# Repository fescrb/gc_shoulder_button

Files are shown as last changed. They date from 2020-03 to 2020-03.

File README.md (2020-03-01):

# GameCube Shoulder Button

This project's aim is to create a model & CAD files of a GameCube shoulder button. 

A 1:1 correspondance is not required. A simple 3D printable model that can be inserted in the hole for the shoulder button and action it in a similar fashion is all that is required.

After the first objective is achieved. The aim is to parameterize travel times for shoulder button activation/deactivation and change them.

# The button

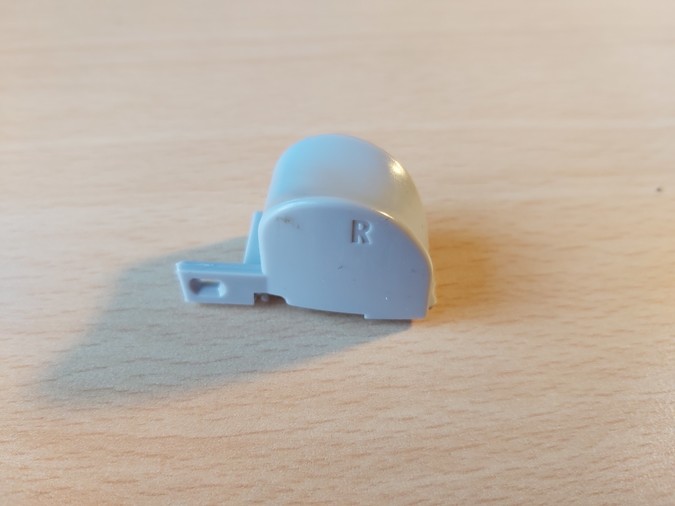
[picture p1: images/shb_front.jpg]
Shoulder Cap - Front


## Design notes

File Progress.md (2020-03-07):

# Progress

# Test 1:

The narrow corner is too big to fit the hole in the controller. Will narrow it down.

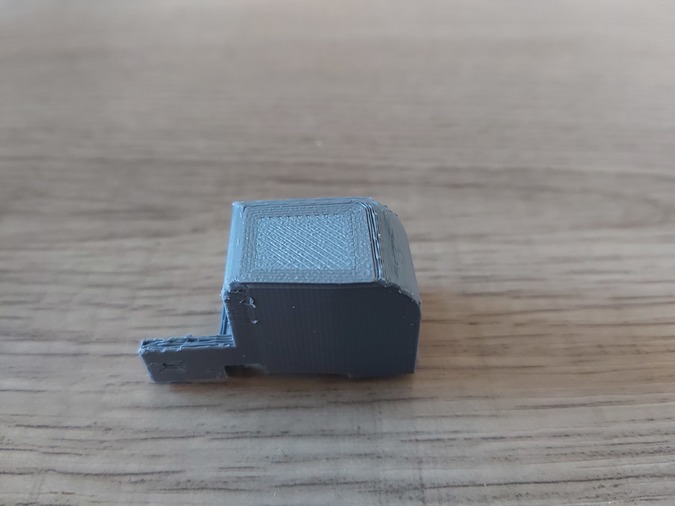
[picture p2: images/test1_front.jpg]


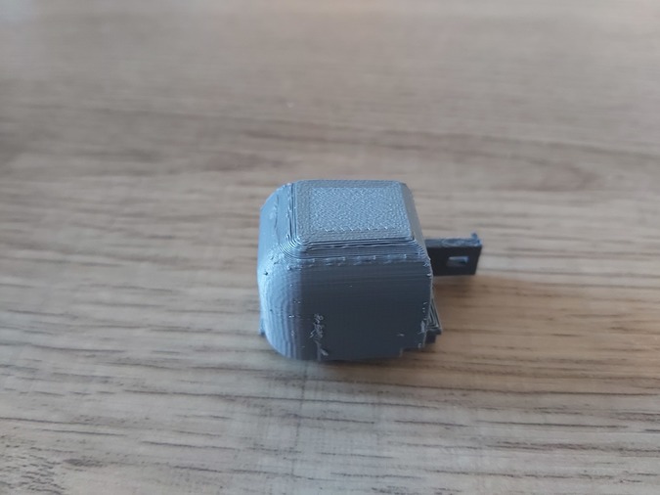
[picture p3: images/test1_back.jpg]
Back


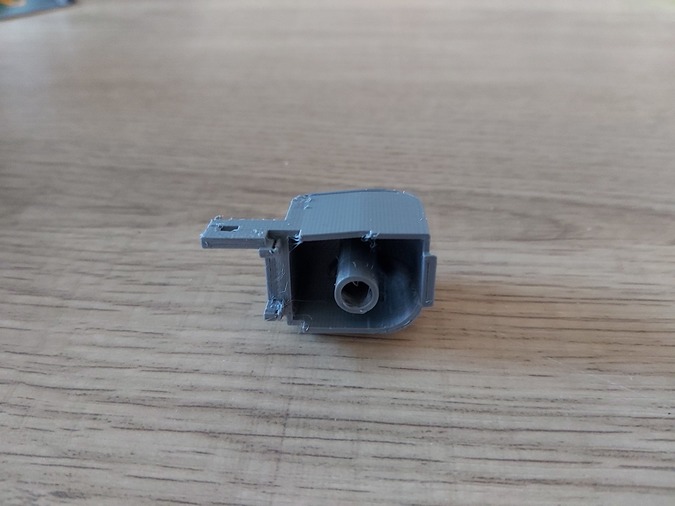
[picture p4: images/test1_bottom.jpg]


# Test 2:

Didn't quite get the top smooth but I did manage to fit the button in the controller.

The clips to attach the spring base are too flimsy at 0.5mm length, I will increase it to 1.5mm and increase the size of the hole that keeps the metal in place.

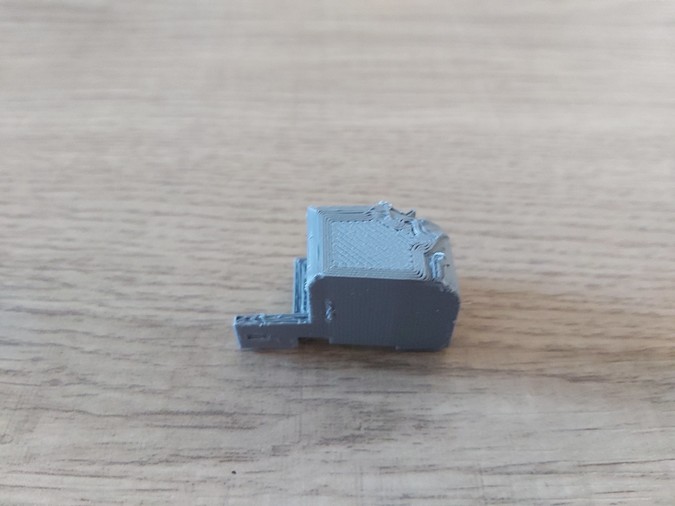
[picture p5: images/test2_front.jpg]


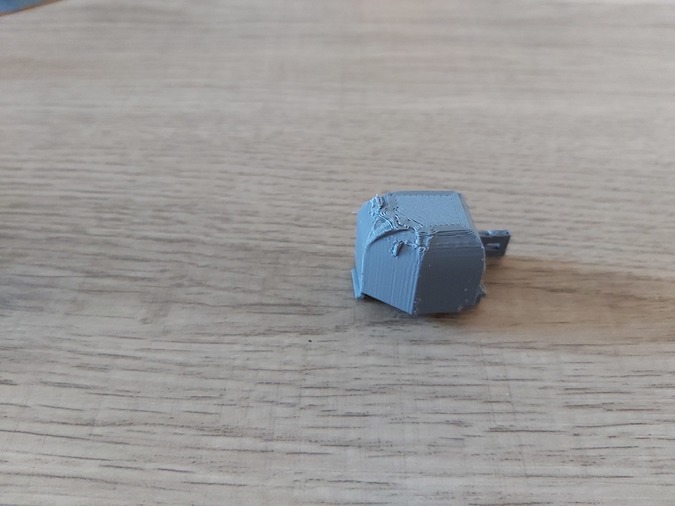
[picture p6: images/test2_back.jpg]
Back


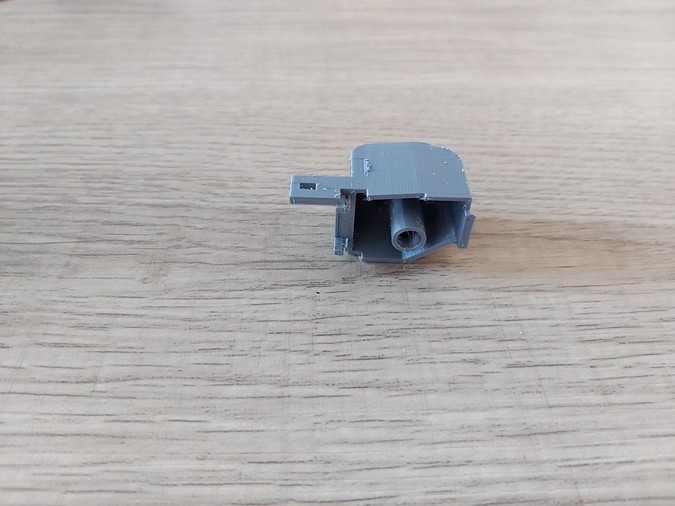
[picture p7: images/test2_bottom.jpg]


# Test 3:

I increased the depth of the clips. However they snapped when trying to connect the metal rail. Unfortunately I forgot to make the cutout go all the way through but I think that had no effect. I'll try making the gap larger to make it easier to slide in the bar, and hopefully less likely to snap.

# Test 4:

The changes to the clips fixed the issue. Now it fits into the slot but when the plastic lid is closed properly it gets stuck. For the next test I will remove one millimeter of depth through the button.

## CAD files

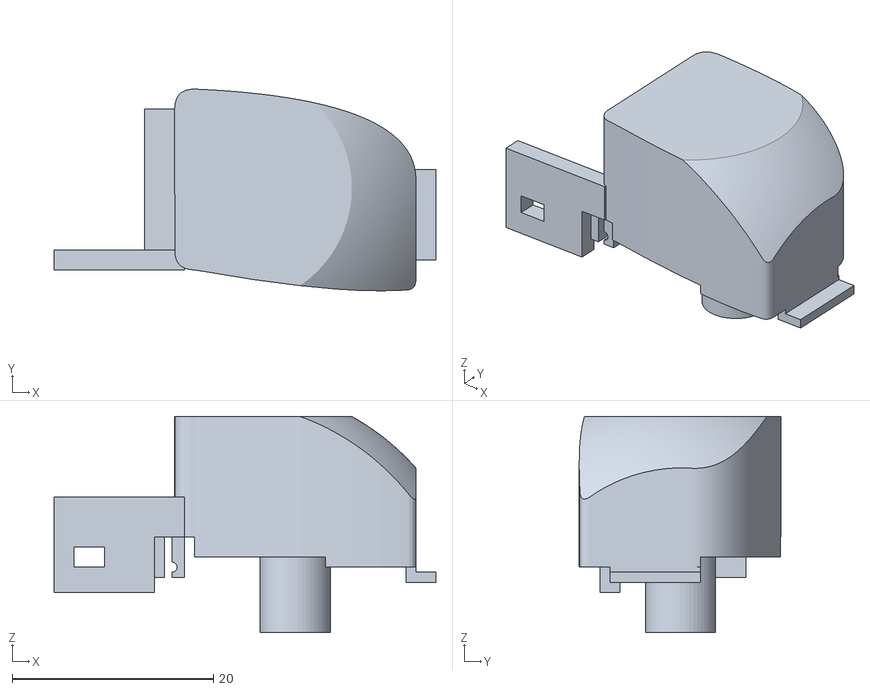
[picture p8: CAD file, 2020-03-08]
shoulder_r_low_action.stl
38.0 x 20.1 x 21.5

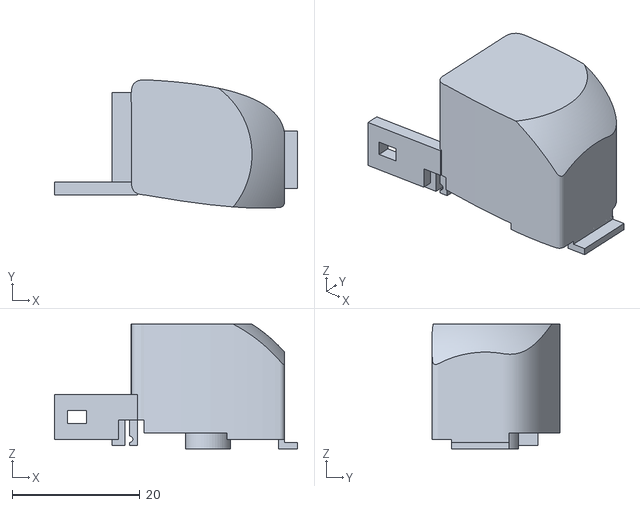
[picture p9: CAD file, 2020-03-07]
shoulder_r_new_shape.stl
38.0 x 20.1 x 19.5

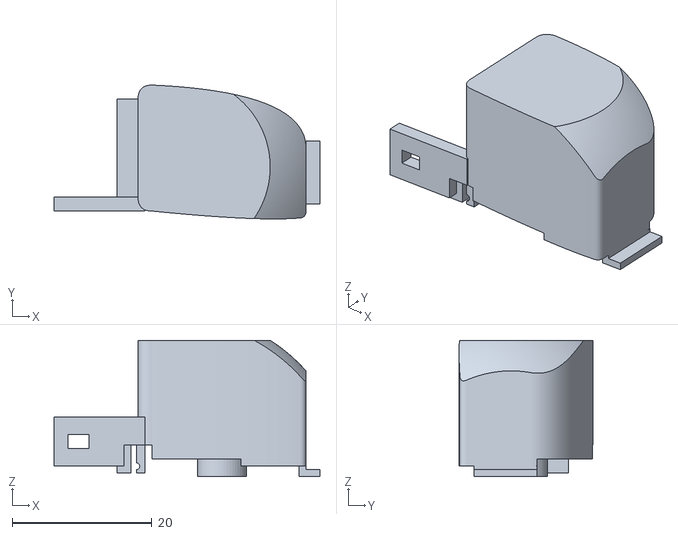
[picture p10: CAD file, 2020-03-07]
shoulder_r.stl
38.0 x 19.1 x 19.5

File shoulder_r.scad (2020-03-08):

use <parts/cap/cap_extruded.scad>
use <parts/lever/lever.scad>
use <parts/clips/clips.scad>
use <parts/lip/lip.scad>
use <parts/tube/tube.scad>

module r_shoulder_button(action_offset, stop_offset){
    cap();
    translate([-12,0,-3]){
        lever(action_offset);
    }
    translate([-3,0,0]){
        clips();
    }
    translate([23,1,-4.5]){
        lip();
    }
    translate([12,8,-4.5]){
        tube(tube_height=13, anchor_height=3, stop_offset=action_offset+stop_offset);
    }
}

r_shoulder_button(2.5,2.5);

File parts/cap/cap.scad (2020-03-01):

$fn=100;
module cap() {
    module cap_shape(width,depth,height) {
        module slanted_cylinder(s_offset,length) {
            translate([width-10,depth,-2]) {
                rotate([0,0,-atan(7/10)]){
                    difference() {
                        translate([s_offset,-7,height-5]) {
                            rotate([0,90,0]){
                                cylinder(r=7,h=length);
                            }
                        }
                        translate([s_offset,-14,0]) {
                            cube([length,7,height]);
                        }
                    }
                }
            }
        }
        module right_cylinder(height_) {
            translate([width-9,-1,-3]){
                difference(){
                    translate([2,0,height-4]){
                        rotate([270,0,0]){
                            cylinder(r=7,h=height_);
                        }
                    }
                    translate([-6,-0.5,0]){
                        cube([6,3,height+3]);
                    }
                }
            }
        }
        module far_cylinder() {
            translate([3,depth-7,height-7]) {
                rotate([0,90,0]){
                    cylinder(r=7,h=width-13);
                }
            }
        }
        module slanted_cube() {
            // Cube that occupies the whole slanted area. 
            // For intersect & diff purposes.
            translate([width-10,depth,-2]) {
                rotate([0,0,-atan(7/10)]){
                    translate([0,-7,0]){
                        cube([l,7,height+2]);
                    }
                }
            }
        }
        // Left corner + rounded top
        cube([3,depth-2,height-3]);
        translate([3,0,height-3]){
            rotate([270,0,0]){
                cylinder(r=3,h=depth-7);
            }
        }
        intersection(){
            translate([3,0,height-3]){
                rotate([270,0,0]){
                    cylinder(r=3,h=depth);
                }
            }
            translate([0,depth-7,height-7]){
                rotate([0,90,0]){
                    cylinder(r=7,h=16);
                }
            }
        }
        translate([0,depth-2,0]){
            cube([3,2,height-7]);
        }
        difference(){
            translate([0,depth-7,height-7]){
                rotate([0,90,0]){
                    cylinder(r=7,h=3);
                }
            }
            
            cube([3,depth-2,height*2]);
        }
        // Middle bit
        translate([3,0,-2]) {
            cube([width-13,depth,height-5]);
            translate([0,0,height-5]){
                cube([width-12,depth-10,7]);
                cube([width-15,depth-7,7]);
            }
            rotate([0,0,-atan(1/11)]){
                cube([sqrt((11*11)+2),2,height+2]);
            }
            //closing some holes
            translate([width-12,-1,height]){
                cube([2,depth-9,2]);
            }
            cube([width-7,depth-7,height-10]);
        }
        // Right straight bit
        translate([width-9,-1,-3]){
            cube([9,depth-6,height-4]);
        }
        // Right-far slant
        l=sqrt((10*10)+(7*7));
        translate([width-10,depth,-2]) {
            rotate([0,0,-atan(7/10)]){
                translate([0,-7,0]){
                    cube([l,7,height-5]);
                    translate([2,-4,2]){
                        cube([l/2,4,height]);
                    }
                }
            }
        }
        slanted_cylinder(l/5,l/2);
        // Right far corner
        intersection() {
            right_cylinder(depth-6);   
            slanted_cylinder(0,l);
        }
        difference(){
            slanted_cylinder(l/2,l/2);
            cube([width,depth-7,height]);
        }
        difference() {
            right_cylinder(depth-6);   
            slanted_cube();
        }
        // middle corner
        intersection() {
            far_cylinder();
            slanted_cylinder(0,l);
        }
        difference() {
            far_cylinder();
            slanted_cube();
        }
        difference(){
            slanted_cylinder(0,l/2);
            cube([width-10,depth,height]);
        }
    }
    difference(){
        cap_shape(width=23,depth=17,height=16);
        translate([1,1,-2]){
            cap_shape(width=21,depth=15,height=17);
        }
    }
}
cap();

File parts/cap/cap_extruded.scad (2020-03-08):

module cap() {
    function lerp(start, end, alpha) = [for (i = [0: len(start)-1]) start[i] + (alpha * (end[i] - start[i]))];
    function lin_bezier(start, end, control, steps) = [ 
        for (i = [1: steps]) lerp(lerp(start, control, i/steps),lerp(control,end,i/steps),i/steps)
    ];
    function concatenate(lhs, rhs) = [for (i = [0 : len(lhs)+len(rhs) -1]) i < len(lhs) ? lhs[i] : rhs[i-len(lhs)]];
    module cap_shape(width,depth,h) {
        // Lhs straight shape
        base_shape0=[[0,2],[0,depth-2]];
        // Add curve at far left
        base_shape1 = concatenate(base_shape0, lin_bezier([0,depth-2],[2,depth],[0,depth],400));
        // Add the back
        base_shape2 = concatenate(base_shape1, lin_bezier([2,depth], [width,depth-9],[width,depth-1],400));
        // Add the right straight shape
        base_shape3 = concatenate(base_shape2, [[width,1]]);
        // Ass the curve at the right front
        base_shape4 = concatenate(base_shape3, lin_bezier([width,-1],[width-1,-2],[width,-2],400));
        // Add the front
        base_shape5 = concatenate(base_shape4, lin_bezier([width-1,-2],[2,0],[width-8,-2.5],400));
        // Add the curve at the front left
        base_shape = concatenate(base_shape5, lin_bezier([2,0],[0,2],[0,0], 400));
        /*
         * Top of the cap
         */
        intersection() {
            linear_extrude(height=h,center=false, twist=0,slices=0) {
                polygon(points=base_shape);
            }
            translate([width*.25, depth*0.45,-h*0.75]){ 
                sphere(r=width, $fn=300);
            }
        }
        translate([0,0,-2]){
            // First tier
            difference() {
                linear_extrude(height=2,center=false, twist=0,slices=0) {
                    polygon(points=base_shape);
                }
                cube([3,depth+2,2]);
            }
            translate([0,0,-1]){
                difference() {
                    linear_extrude(height=1,center=false, twist=0,slices=0) {
                        polygon(points=base_shape);
                    }
                    translate([0,-2,0]){
                        union() {
                            cube([width-9,depth+4,1]);
                            translate([width-9,12,0]){
                                cube([9,depth-10,1]);
                            }
                        }
                    }
                }
            }
        }
    }
    difference(){
        cap_shape(width=24,depth=18,h=12);
        translate([1,1,-2]){
            cap_shape(width=22,depth=16,h=13);
        }
    }
}
cap();

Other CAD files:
parts/clips/clips.scad
parts/lever/lever.scad
parts/lip/lip.scad
parts/tube/tube.scad

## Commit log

2020-03-01 Attemp to fix the part that doesn't fit. Clean up later.
    [cap.scad]
2020-03-01 Increased the thickness of the clips.
    [cap.scad, clips.scad, shoulder_r.stl]
2020-03-01 Stop the tube anchor from intersecting the cap
    [tube.scad]
2020-03-01 Increased the depth of the clips
    [cap.scad, clips.scad, shoulder_r.stl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]
2020-03-01 Increased gap between clips and noted 3rd test.
    [clips.scad, shoulder_r.stl]
2020-03-01 Reduce depth throughout.
    [cap.scad, lip.scad, shoulder_r.scad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]
2020-03-03 Action/stop movable.
    [lever.scad, shoulder_r.scad, tube.scad]
2020-03-07 Bezier function definitions.
    [cap_extruded.scad]
2020-03-07 Finished bezier implementation.
    [cap_extruded.scad, shoulder_r.scad]
2020-03-07 Redo beziers after test
    [cap_extruded.scad, shoulder_r.stl, tube.scad]
2020-03-07 Tweak geometry further
    [cap_extruded.scad, lever.scad, shoulder_r.stl]
2020-03-07 Low action version of the button test
    [shoulder_r.scad, shoulder_r_low_action.stl]
2020-03-07 New tests
    [cap_extruded.scad, shoulder_r.scad, shoulder_r_low_action.stl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]
2020-03-08 Reduce the stop by 2mm. Make the button shorter & parameterize the tube
    [cap_extruded.scad, shoulder_r.scad, shoulder_r_low_action.stl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]
